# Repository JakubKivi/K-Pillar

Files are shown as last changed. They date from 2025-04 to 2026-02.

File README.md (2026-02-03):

# K-Pillar

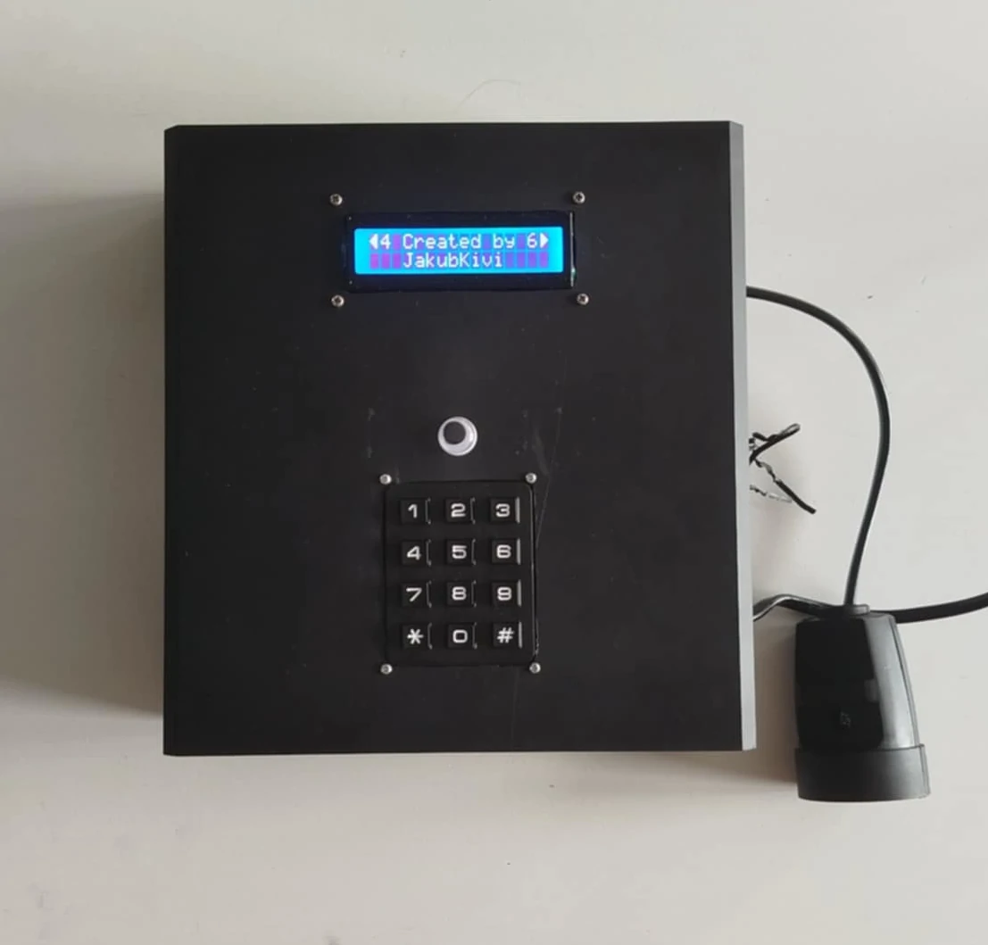
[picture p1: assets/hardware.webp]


K-Pillar is a fully automated plant watering system controlled by an Arduino Nano with a custom expansion board. It supports up to three independent watering schedules configurable via an LCD and keypad interface, with all settings saved to EEPROM for power-loss resilience. The system also includes a programmable relay for controlling additional devices like grow lights, and is designed with low-power consumption in mind using efficient C++ classes.

More info [here](https://jakubkivi.github.io#portfolio-modal-k-pillar)

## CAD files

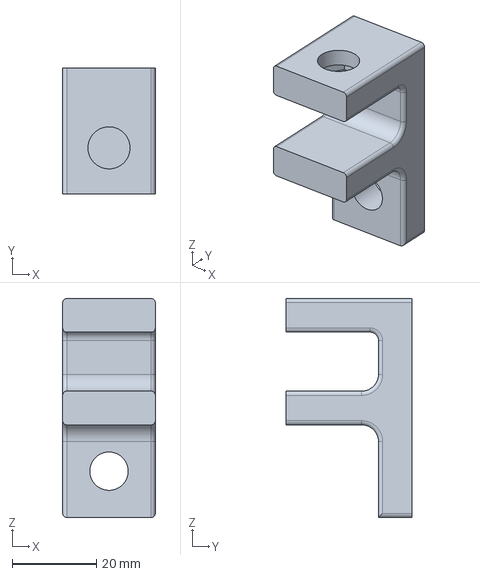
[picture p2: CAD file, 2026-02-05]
FreeCAD/PipeHolder.FCStd
22.0 x 30.0 x 52.0 mm

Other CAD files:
FreeCAD/PipeHolder.stl

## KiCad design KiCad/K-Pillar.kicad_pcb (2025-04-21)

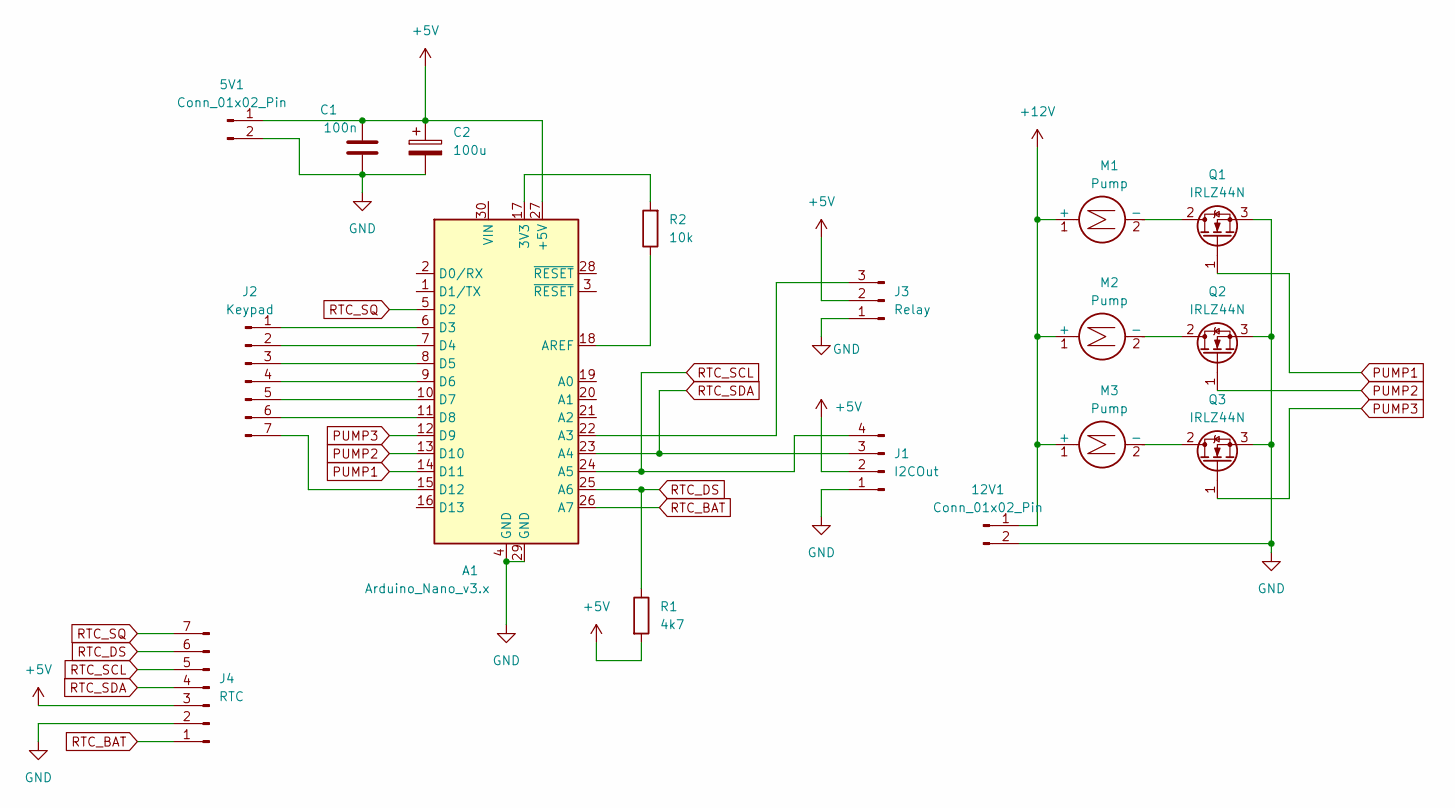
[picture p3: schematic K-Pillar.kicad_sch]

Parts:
5V1, 12V1: Conn_01x02_Pin; PinHeader_1x02_P2.54mm_Vertical
A1: Arduino_Nano_v3.x; Arduino_Nano
C1: 100n; C_0805_2012Metric_Pad1.18x1.45mm_HandSolder
C2: 100u; CP_Radial_D5.0mm_P2.50mm
J1: I2COut; PinHeader_1x04_P2.54mm_Vertical
J2: Keypad; PinHeader_1x07_P2.54mm_Vertical
J3: Relay; PinHeader_1x03_P2.54mm_Vertical
J4: RTC; PinHeader_1x07_P2.54mm_Vertical
M1, M2, M3: Pump; TerminalBlock_4Ucon_1x02_P3.50mm_Horizontal
Q1, Q2, Q3: IRLZ44N; TO-220-3_Vertical
R1: 4k7; R_0805_2012Metric_Pad1.20x1.40mm_HandSolder
R2: 10k; R_0805_2012Metric_Pad1.20x1.40mm_HandSolder

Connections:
+5V: 5V1.1, A1.27 (+5V), C1.2, C2.1, J1.2, J3.2, J4.3, R1.2
+12V: 12V1.1, M1.1 (+), M2.1 (+), M3.1 (+)
GND: 5V1.2, 12V1.2, A1.4 (GND), A1.29 (GND), C1.1, C2.2, J1.1, J3.1, J4.2, Q1.3 (S), Q2.3 (S), Q3.3 (S)
unnamed: A1.17 (3V3), R2.2
unnamed: A1.22 (A3), J3.3
unnamed: A1.18 (AREF), R2.1
unnamed: A1.6 (D3), J2.1
unnamed: A1.7 (D4), J2.2
unnamed: A1.8 (D5), J2.3
unnamed: A1.9 (D6), J2.4
unnamed: A1.10 (D7), J2.5
unnamed: A1.11 (D8), J2.6
unnamed: A1.15 (D12), J2.7
unnamed: M1.2 (-), Q1.2 (D)
unnamed: M2.2 (-), Q2.2 (D)
unnamed: M3.2 (-), Q3.2 (D)
PUMP1: A1.14 (D11), Q1.1 (G)
PUMP2: A1.13 (D10), Q2.1 (G)
PUMP3: A1.12 (D9), Q3.1 (G)
RTC_BAT: A1.26 (A7), J4.1
RTC_DS: A1.25 (A6), J4.6, R1.1
RTC_SCL: A1.24 (A5), J1.4, J4.5
RTC_SDA: A1.23 (A4), J1.3, J4.4
RTC_SQ: A1.5 (D2), J4.7

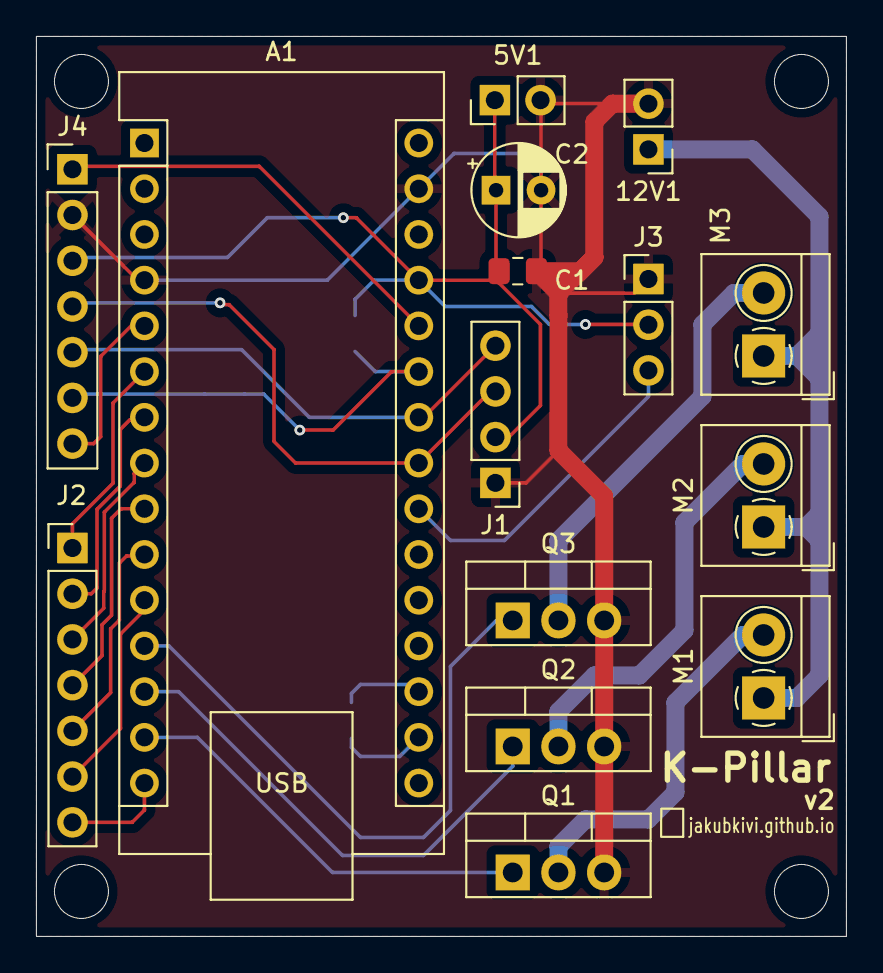
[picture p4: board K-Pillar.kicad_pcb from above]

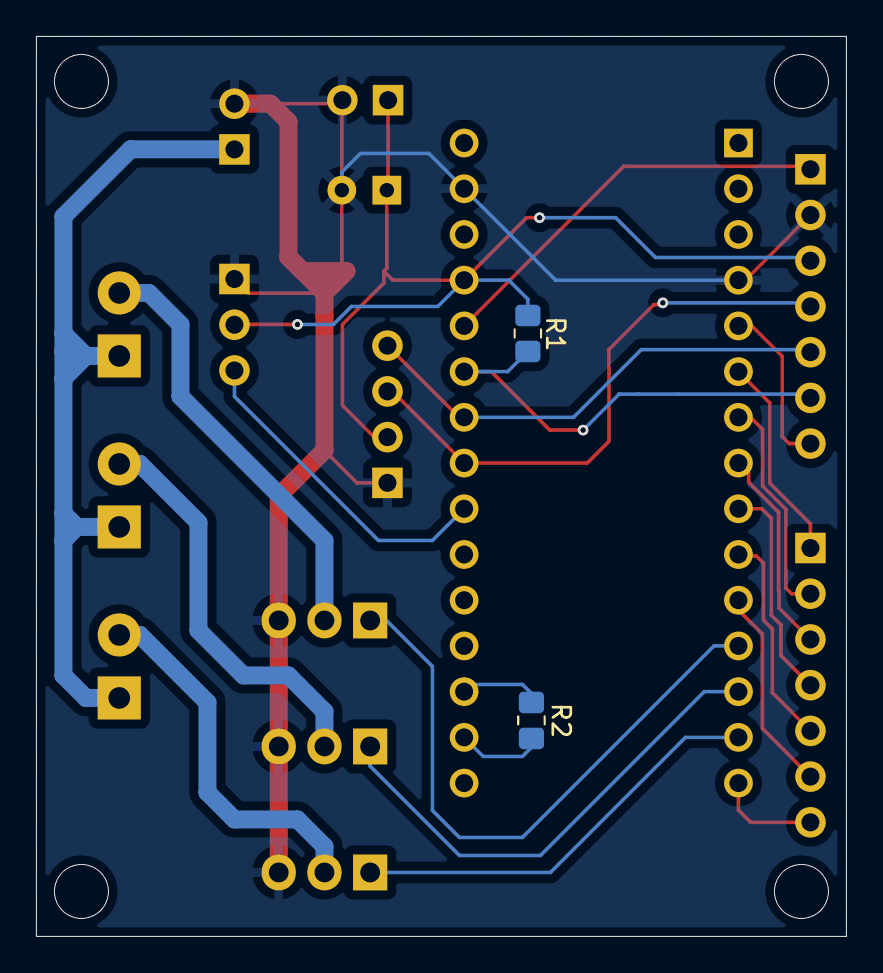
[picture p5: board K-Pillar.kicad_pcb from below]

Board: 2 copper layers, 45.0 x 50.0 mm, 17 parts (2 on the bottom side), 24 nets.

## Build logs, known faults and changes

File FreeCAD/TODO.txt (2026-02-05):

Kupić rurki/wężyki z abcrc https://abc-rc.pl/pl/products/rurka-silikonowa-7mm-9mm-do-mini-pomp-wody-projektow-diy-1mb-11554.html

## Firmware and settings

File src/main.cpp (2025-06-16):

#include <Arduino.h>
#include <Wire.h>
#include <LiquidCrystal_I2C.h>
#include <Keypad.h>
#include "hardware/Pump.h"
#include "hardware/Relay.h"
#include "logic/Schedule.h"
#include "ui/Menu.h"
#include "power/PowerManager.h"
#include <Wire.h>
#include <I2C_RTC.h>
#include "hardware/EepromControl.h"
#include "logic/DateStruct.h"
#include "logic/RelaySchedule.h"

#define NUM_SCHEDULES 3

static DS1307 RTC;

EepromControl EEPROM;

LiquidCrystal_I2C lcd(0x27, 16, 2);

const byte ROWS = 4;
const byte COLS = 3;
char keys[ROWS][COLS] = {
    {'1', '2', '3'},
    {'4', '5', '6'},
    {'7', '8', '9'},
    {'*', '0', '#'}};

byte rowPins[ROWS] = {4, 12, 8, 6};
byte colPins[COLS] = {5, 3, 7};

Keypad keypad = Keypad(makeKeymap(keys), rowPins, colPins, ROWS, COLS);

Pump pump1(9, 1);
Pump pump2(10, 2);
Pump pump3(11, 3);
Relay relay(A3);

Schedule schedule1(&pump1, &EEPROM, &lcd);
Schedule schedule2(&pump2, &EEPROM, &lcd);
Schedule schedule3(&pump3, &EEPROM, &lcd);

RelaySchedule relaySchedule(&relay, &EEPROM, &lcd);

Schedule *schedules[] = {&schedule1, &schedule2, &schedule3, &relaySchedule};
PowerManager powerManager(&lcd, &keypad, 15000);
Menu menu(&lcd, &keypad, schedules, &RTC, &powerManager, &EEPROM);

void setup()
{

    bool enabled[NUM_SCHEDULES];
    unsigned int intervalDays[NUM_SCHEDULES];
    TimeStruct times[NUM_SCHEDULES];
    unsigned long waterAmmount[NUM_SCHEDULES];
    DateStruct nextWatering[NUM_SCHEDULES];

    // EEPROM.writeSchedule(0, 0, 2, TimeStruct(15,0), 3000, DateStruct(26,5,2025));
    // EEPROM.writeSchedule(1, 0, 3, TimeStruct(16,0), 6000, DateStruct(27,5,2025));
    // EEPROM.writeSchedule(2, 0, 4, TimeStruct(18,0), 8000, DateStruct(28,5,2025));

    //EEPROM.writeRelaySchedule(0, TimeStruct(18, 0), TimeStruct(22, 0));

    EEPROM.readAllSchedules(enabled, intervalDays, times, waterAmmount, nextWatering);
    for (int i = 0; i <= 2; i++)
    {
        schedules[i]->setValues(enabled[i], intervalDays[i], times[i], waterAmmount[i], nextWatering[i]);
    }

    bool rEnabled;
    TimeStruct rTime;
    TimeStruct rTimeOff;

    EEPROM.readRelaySchedule(&rEnabled, &rTime, &rTimeOff);

    relaySchedule.setValues(rEnabled, rTime, rTimeOff);

    uint16_t noInteractionThreshhold;
    EEPROM.readSettings(noInteractionThreshhold);
    powerManager.setNoInteractionThreshhold(noInteractionThreshhold);

    Serial.begin(9600);
    lcd.init();
    powerManager.wakeUp();
    menu.lcdCreateCustomCharacters();
    menu.lcdCreateHomeScreen();
    menu.displayScreen();

    RTC.begin();
    if (RTC.isConnected() == false)
    {
        Serial.println("RTC Not Connected!");
    }
    else
    {
        if (!RTC.isRunning())
        {
            RTC.startClock();
        }
    }
    tm read = RTC.getDateTime();
    menu.setCurrentTime(TimeStruct(read.tm_hour, read.tm_min), false);
    menu.setCurrentDate(DateStruct(read.tm_mday, read.tm_mon, 1900 + read.tm_year), false);

    // RTC.setWeek(3);
    // RTC.setDate(20,05,25);
    // RTC.setTime(19,29,0);

    char key = keypad.getKey();
    if (key == '*')
    {
        menu.adminFlag = true;
    }
}

unsigned int counter = 0;

void loop()
{
    if (powerManager.update())
    {
        menu.displayScreen();
    }
    
    char key = keypad.getKey();

    if (key)
    {
        powerManager.resetTimer();

        if (powerManager.isSilentWakeUp)
        {
            powerManager.isSilentWakeUp = false;
            lcd.backlight();
        }
        else
        {
            menu.update(key);
        }
    }

    counter++;
    if (counter > 100) //~10 sec
    {
        counter = 0;
        // Serial.println(RTC.getDateTimeString());
        // DateStruct a = menu.getCurrentDate();
        // Serial.println(String(a.day)+"."+a.month+"."+a.year);
        tm read = RTC.getDateTime();
        menu.setCurrentTime(TimeStruct(read.tm_hour, read.tm_min), false);
        menu.setCurrentDate(DateStruct(read.tm_mday, read.tm_mon + 1, 1900 + read.tm_year), false);
        
        TimeStruct time = menu.getCurrentTime();
        DateStruct date = menu.getCurrentDate();

        if (!menu.adminFlag)
        {
            if (schedule1.update(time, date) or schedule2.update(time, date) or schedule3.update(time, date))
                menu.displayScreen(powerManager.isSilentWakeUp);
            relaySchedule.update(time, date);
        }
    }


    delay(100);
}

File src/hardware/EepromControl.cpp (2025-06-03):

#include "EepromControl.h"

#include <Arduino.h>
#include "logic/TimeStruct.h"

EepromControl::EepromControl() {
    Wire.begin();
}

void EepromControl::Ewrite(unsigned int addr, byte data) {
    Wire.beginTransmission(EEPROM_ADDR);
    Wire.write((int)(addr >> 8));
    Wire.write((int)(addr & 0xFF));
    Wire.write(data);
    Wire.endTransmission();
    delay(5);
}

byte EepromControl::Eread(unsigned int addr) {
    Wire.beginTransmission(EEPROM_ADDR);
    Wire.write((int)(addr >> 8));
    Wire.write((int)(addr & 0xFF));
    Wire.endTransmission();

    Wire.requestFrom(EEPROM_ADDR, 1);
    if (Wire.available()) return Wire.read();
    return 0xFF;
}

void EepromControl::writeUInt16(unsigned int addr, uint16_t value) {
    Ewrite(addr, value >> 8);
    Ewrite(addr + 1, value & 0xFF);
}

uint16_t EepromControl::readUInt16(unsigned int addr) {
    return (Eread(addr) << 8) | Eread(addr + 1);
}

void EepromControl::writeUInt32(unsigned int addr, uint32_t value) {
    for (int i = 0; i < 4; i++) {
        Ewrite(addr + i, (value >> (8 * (3 - i))) & 0xFF);
    }
}

uint32_t EepromControl::readUInt32(unsigned int addr) {
    uint32_t val = 0;
    for (int i = 0; i < 4; i++) {
        val <<= 8;
        val |= Eread(addr + i);
    }
    return val;
}

unsigned int EepromControl::getScheduleBaseAddr(uint8_t index) {
    return index * 16;  
}

void EepromControl::writeSchedule(uint8_t index, bool enabled, unsigned int intervalDays, const TimeStruct& time, unsigned long waterAmmount, DateStruct nextWatering) {
    unsigned int base = getScheduleBaseAddr(index);
    Ewrite(base, enabled ? 1 : 0);
    writeUInt16(base + 1, intervalDays);
    Ewrite(base + 3, time.hour);
    Ewrite(base + 4, time.minute);
    Ewrite(base + 5, nextWatering.day);
    Ewrite(base + 6, nextWatering.month);
    writeUInt16(base + 7, nextWatering.year);
    writeUInt32(base + 9, waterAmmount);

}

void EepromControl::writeRelaySchedule( bool enabled, TimeStruct time, TimeStruct timeOff){
    unsigned int base = getScheduleBaseAddr(NUM_SCHEDULES+1);

    Ewrite(base, enabled ? 1 : 0);
    Ewrite(base + 1, time.hour);
    Ewrite(base + 2, time.minute);
    Ewrite(base + 3, timeOff.hour);
    Ewrite(base + 4, timeOff.minute);
}

void EepromControl::readAllSchedules(bool enabled[], unsigned int intervalDays[], TimeStruct times[], unsigned long waterAmmount[], DateStruct nextWatering[]) {
    for (uint8_t i = 0; i < NUM_SCHEDULES; i++) {
        unsigned int base = getScheduleBaseAddr(i);
        enabled[i] = Eread(base) != 0;
        intervalDays[i] = readUInt16(base + 1);
        times[i].hour = Eread(base + 3);
        times[i].minute = Eread(base + 4);
        nextWatering[i].day = Eread(base+5);
        nextWatering[i].month = Eread(base+6);
        nextWatering[i].year = readUInt16(base+7);
        waterAmmount[i] = readUInt32(base + 9);
    }
}

void EepromControl::readRelaySchedule(bool *enabled, TimeStruct *time, TimeStruct *timeOff){
    unsigned int base = getScheduleBaseAddr(NUM_SCHEDULES+1);

    *enabled = Eread(base); 
    time->hour = Eread(base + 1);
    time->minute = Eread(base + 2);
    timeOff->hour = Eread(base + 3);
    timeOff->minute = Eread(base + 4);
}


void EepromControl::saveSettings(uint16_t setting1) {
    writeUInt16(SETTINGS_BASE_ADDR, setting1);   
}

void EepromControl::readSettings(uint16_t& setting1) {
    setting1 = readUInt16(SETTINGS_BASE_ADDR);
}

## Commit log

2025-02-25 started kicad project
    [K-Pillar.kicad_pcb, K-Pillar.kicad_sch]
2025-02-28 płytka zrobiona można na narty
    [K-Pillar-B_Cu.gbr, K-Pillar-B_Mask.gbr, K-Pillar-B_Paste.gbr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]
2025-04-15 started working on v2 board
    [K-Pillar.kicad_sch]
2025-04-21 board v2
    [K-Pillar-B_Cu.gbr, K-Pillar-B_Mask.gbr, K-Pillar-B_Paste.gbr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]
2025-05-06 new board working
    [K-Pillar.kicad_pcb]
2025-05-07 przywrócenie kicada bo idk co sie stalo ale nic nie bylo + RTC działa w głównym kodzie
    [K-Pillar.kicad_pcb]
2025-06-02 relayschedule i 3 pompki
2025-06-03 socket logic almost done
2025-06-17 finished with new keypad, debugged, closing frame
2026-02-03 pipe holder added
    [PipeHolder.FCStd]
2026-02-03 pipe holder v1
    [PipeHolder.FCStd]
2026-02-03 improvements in pipeholder
    [PipeHolder.FCStd, PipeHolder.stl]
2026-02-05 updated pipeholder
    [PipeHolder.FCStd]
